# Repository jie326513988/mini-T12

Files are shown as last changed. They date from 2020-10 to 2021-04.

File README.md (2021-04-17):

# Mini T12焊台-基于Arduino平台-Atmege328p-au
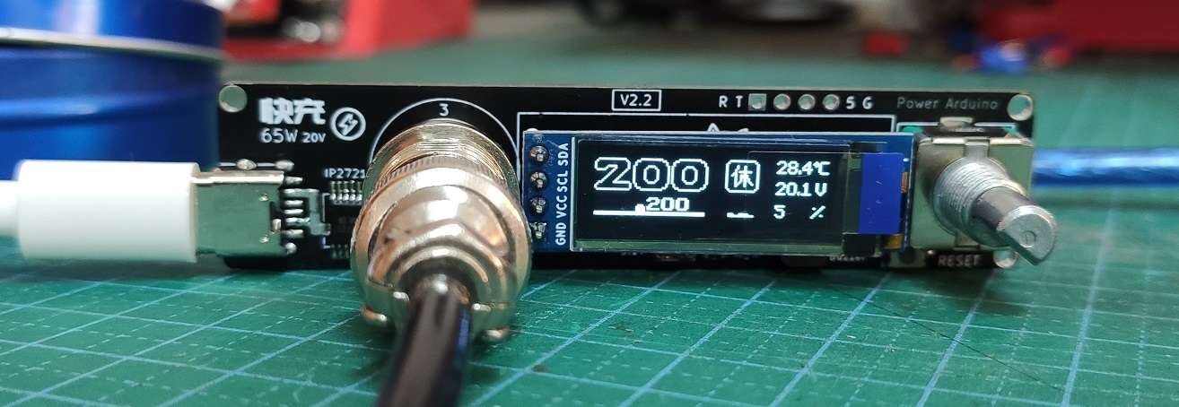
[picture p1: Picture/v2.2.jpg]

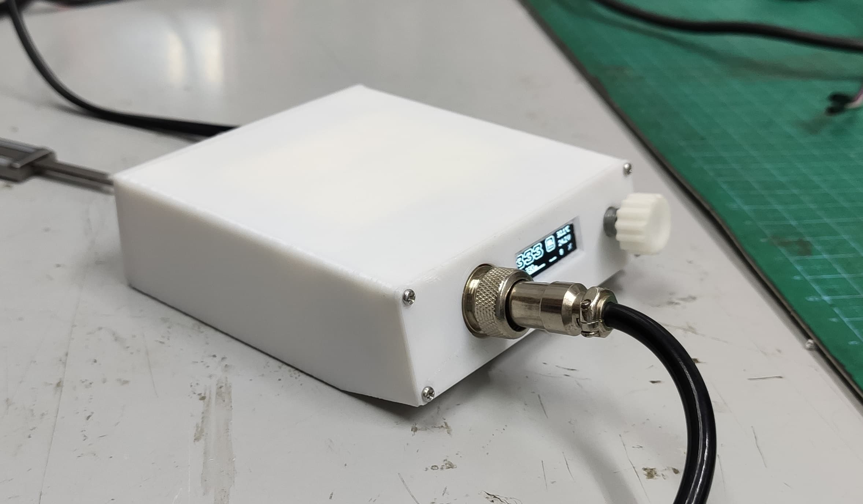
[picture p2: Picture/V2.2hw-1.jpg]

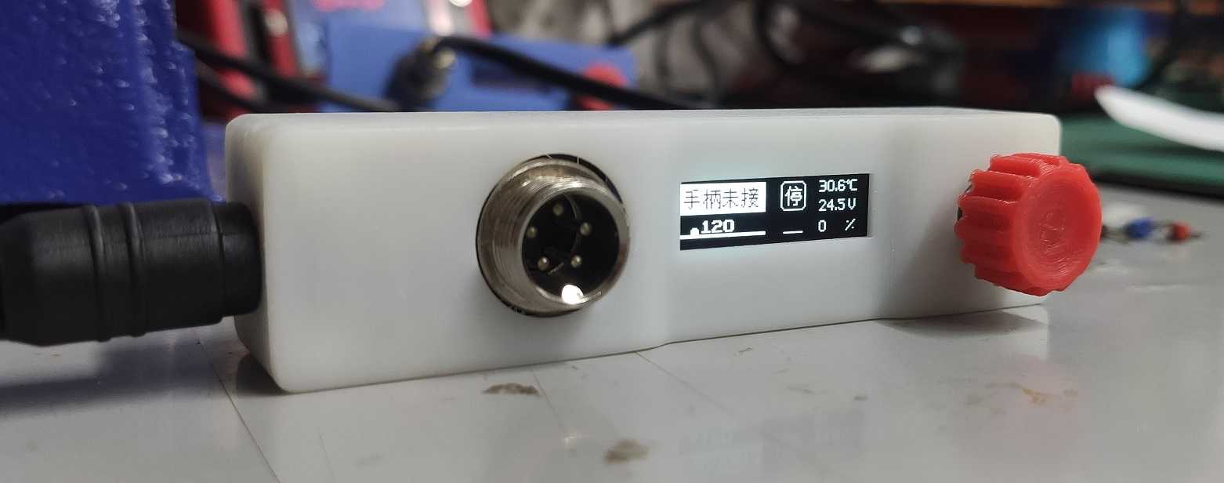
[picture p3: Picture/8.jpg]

### 2021-04-17 V2.2适配华为音响电源一体版的3D打印外壳文件放出
### 2021-04-14 V2.2pd诱骗版本 需将诱骗芯片处100K电阻（接地的那一颗）改为300K，另外一颗不需要改。
### 2021-03-21 V1.20程序更新
* 1.修正温度动画

### 2021-03-20 V1.20程序更新
* 1.主界面温度添加线性化动画
* 2.修改蜂鸣器端口配置策略，停止后改为输入模式
* 3.缩小字库删减不需要的字符并将字库放在本地调用
* 4.休眠时间可以关闭，小于30秒为关闭

#### 默认支持深圳头，更换其他厂商的头需要自行校准温度曲线
#### 一定要使用我提供的U8g2库，否者无法显示中文和提示内存过大无法编译
#### 缺点就是PID温控超调回正时间过长，有能力的小伙伴可自己调节pid参数。
#### 本人喜欢温度显示真实一点，故采用显示平均温度的方案（8次温度采样的平均值）。
#### 当设定温度和平均温度的差值<=3度时就显示平均温度，所以看着会上下浮动1-2度是正常的。
#### 新烙铁头要经过老化温度才能稳定
* 可以在菜单设置里旋转屏幕显示的方向，方便不同的人群
* 动态调参PID
* 稳定时显示5次采集到的平均温度，其他时候显示实时温度大概500ma刷新一次
* 取消电流传感器，主界面取消电流显示改为显示PWM百分比
* 使用4段温度拟合温度曲线，4项式公式计时，可在设置菜单“校准”选项调整
* 休眠计时和息屏倒计时改用定时器2计时
* 息屏显示，无加热无操作3分钟后进入，息屏时显示环境温度，随机平滑移动
* 开机提示音和平滑过渡的开机界面
* 休眠时自动保存当前设置温度到eeprom
* 待机功耗8.8ma 息屏待机功耗6.4ma（24）
#### 观看视频 https://www.bilibili.com/video/BV1vf4y1B7Xa
#### 按键功能定义
* 长按操作（5下短音最后1下长音）
  * 主界面，进入设置界面
  * 其他界面，退出至主界面
* 双击操作（2下短音）
  * 主界面，加热或停止状态切换
  * 其他界面，无
* 单击（1下短音）
  * 主界面，无
  * 设置界面，进入二级菜单
  * 二级菜单，切换数值更改选中状态，或确认更改数值，无选框状态则退出至一级菜单
#### 菜单选项
* PID
  * P
  * I
  * D
* 休眠
  * 休眠时间
  * 休眠温度
* 屏幕
  * 屏幕亮度
  * 屏幕方向
  * 编码器方向
* 电源
  * 基准电压
  * 电源电压
  * 低压报警
* 校准
  * 调节曲线第1段温度
  * 调节曲线第2段温度
  * 调节曲线第3段温度
  * 调节曲线第4段温度
  * 运行曲线拟合程序校准温度曲线
* 烙铁
  * 冷端补偿
  * 开机加热
  * 重置
#### 校准温度曲线的方法
* 1.先校准基准电压，测量串口的5V接口就是基准电压
* 2.准备好能测量0-500摄氏度的设备，探头建议使用裸装，以免外壳热传导导致热量损失测量不准
* 3.将探头紧压住烙铁头发热前段（上锡部分再下来一点），一定要紧紧压住，不然也会测量不准
* 4.放置好烙铁头以免校准时烫伤手或物品！
* 5.接上电源，进入‘烙台’界面，将室温设置为当前的冷端补偿温度，再进入‘校准’界面，将空心选框移动至第1段温度处（即对应的ADC 10下面）
* 6.按下确认键，此时空心选框变成实心选框，烙铁头开始加热，等待最下方的‘Now ADC’值稳定在一定的范围，与第一行相应的ADC值差不多即可（此时是ADC 10）
* 7.使用测量设备测量烙铁头的温度，将第1段温度调至测量得到的温度（实心选框状态可旋转旋钮调节数值）
* 8.依次测量剩下的第2段、第3段、第4段温度并输入至控制器
* 9.测量完4段温度后将光标移至Save，按下确认键，等待程序计时温度曲线
* 10.计算完会显示P系数界面，，再按下确认键即可退出校准界面
* 11.在主界面准备进行二次校准
* 12.在主界面开启加热至第二段校准的温度，如265，则加热至260度，若不对则进入校准界面加减对应的计算温度，直至自己满意为止。
* 13.依次加热至第三、第四、第一、第四段温度并校准，直至自己满意为止。

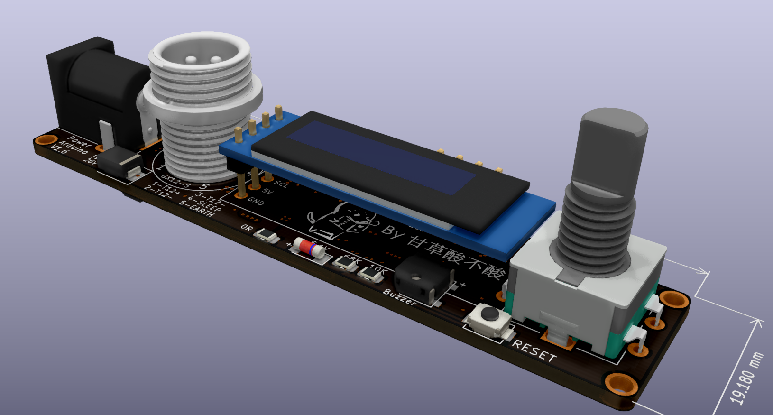
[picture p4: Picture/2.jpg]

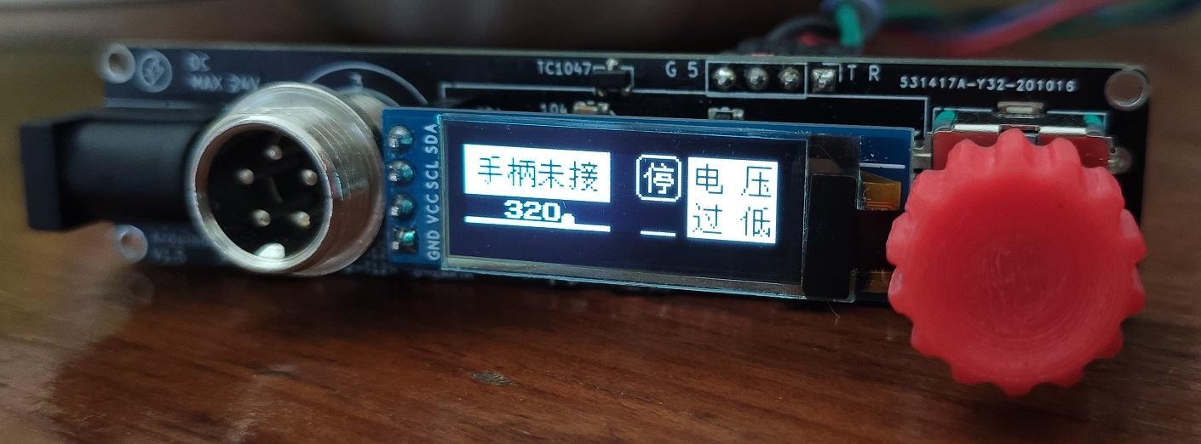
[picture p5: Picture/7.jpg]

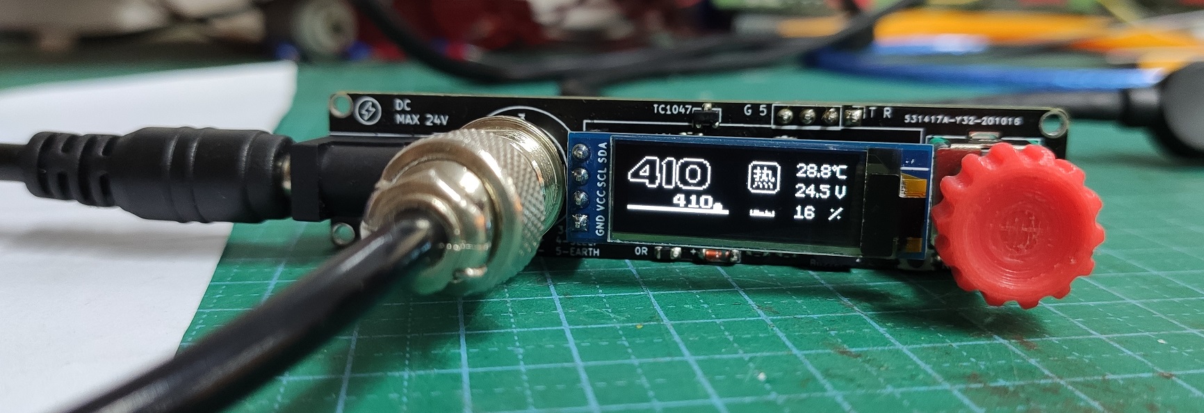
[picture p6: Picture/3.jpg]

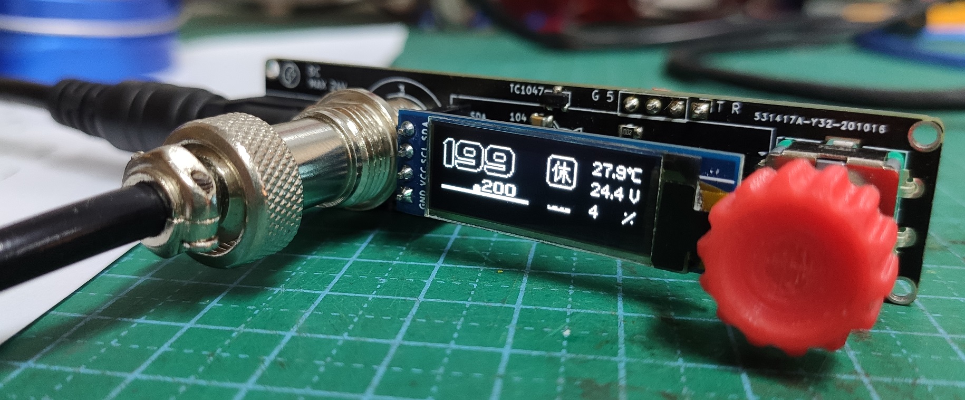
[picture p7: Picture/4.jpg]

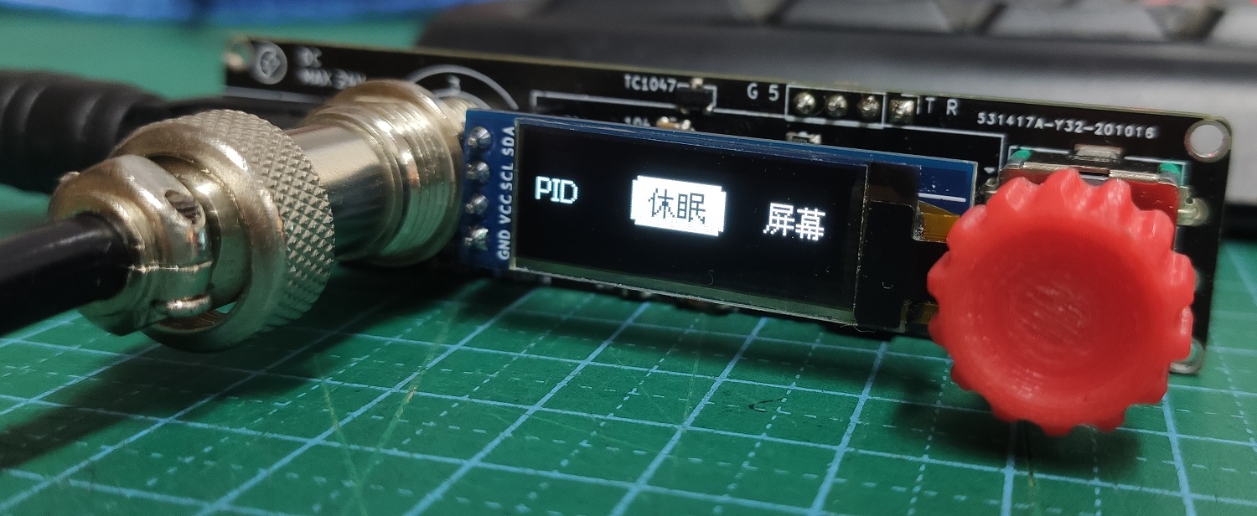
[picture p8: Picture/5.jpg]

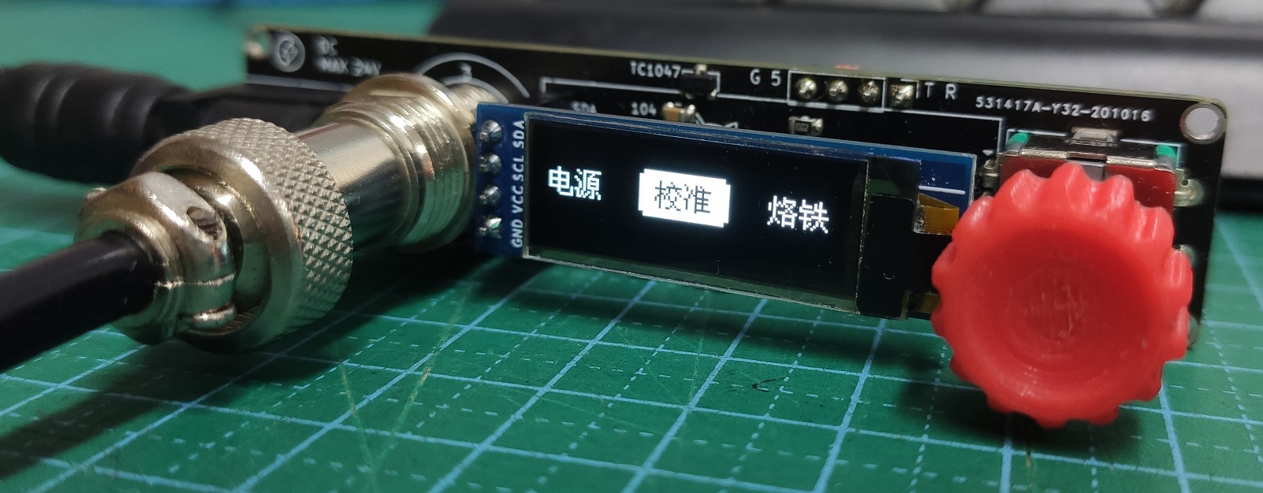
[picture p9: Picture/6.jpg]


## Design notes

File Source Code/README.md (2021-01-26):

## pcb v2.2以后的版本只能使用V1.1以上的程序
## 程序1.03为V1.X的pcb使用

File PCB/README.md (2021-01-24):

#### V2.2pd诱骗版本，优化DCDC线路不烧芯片。

#### 元件要求
* 所有电容首选X7R为佳，其次X5R，千万不要选择Y5V
* DCDC的10UF输入电容使用耐压35V以上
* LP2985的105、104输入电容选择耐压16V以上
* 运放的采样电阻33KΩ和10KΩ使用0.1%精度
* 电压采样电阻68K和10K使用1%精度
* C10,C12,C18耐压16V以上
* 104电容通通耐压50V就行，222电容也耐压50V
* 电阻电容选择0603封装更好焊接
* 磁珠100MHZ阻抗1K,电流100ma以上

#### 用了V1.7PCB的朋友请看下面即可正常使用
* 移除26V的TVS管（D3）
* 移除靠近单片机的10uh电感，改成直连
* 三极管附近的10Ω（R3）电阻改为4.7KΩ，10KΩ电阻改为4.7KΩ（R4）

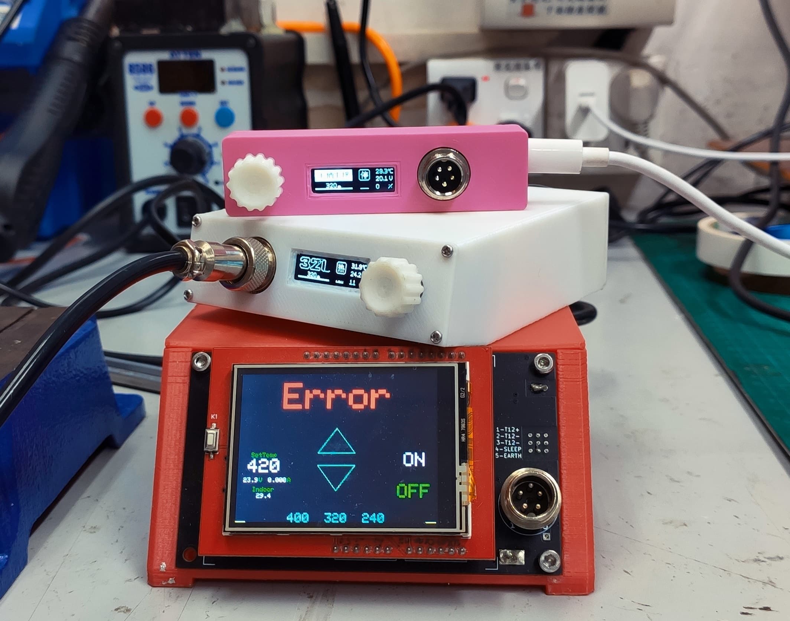
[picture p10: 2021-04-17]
Picture/qjf.jpg

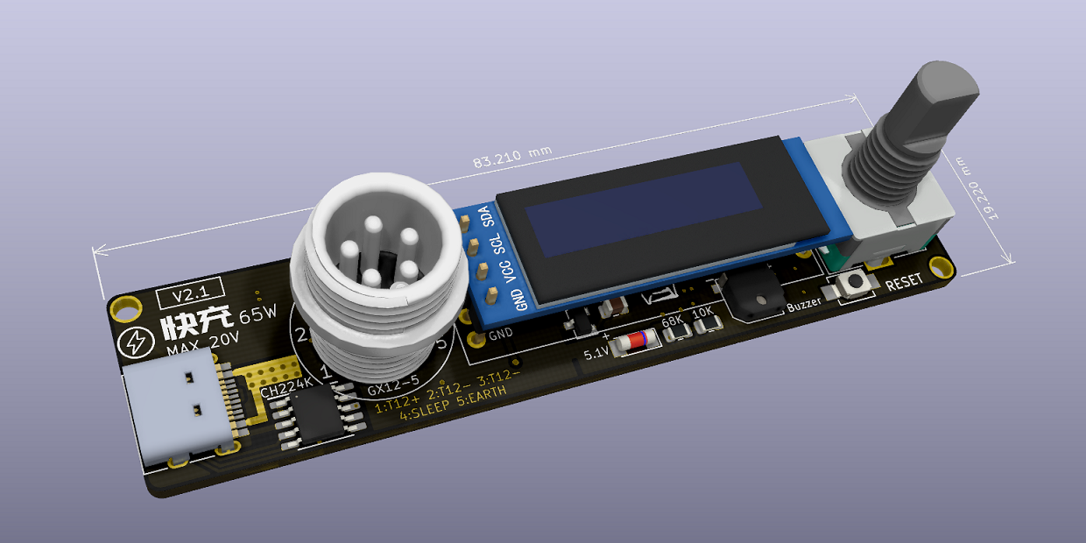
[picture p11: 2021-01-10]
Picture/65W.jpg

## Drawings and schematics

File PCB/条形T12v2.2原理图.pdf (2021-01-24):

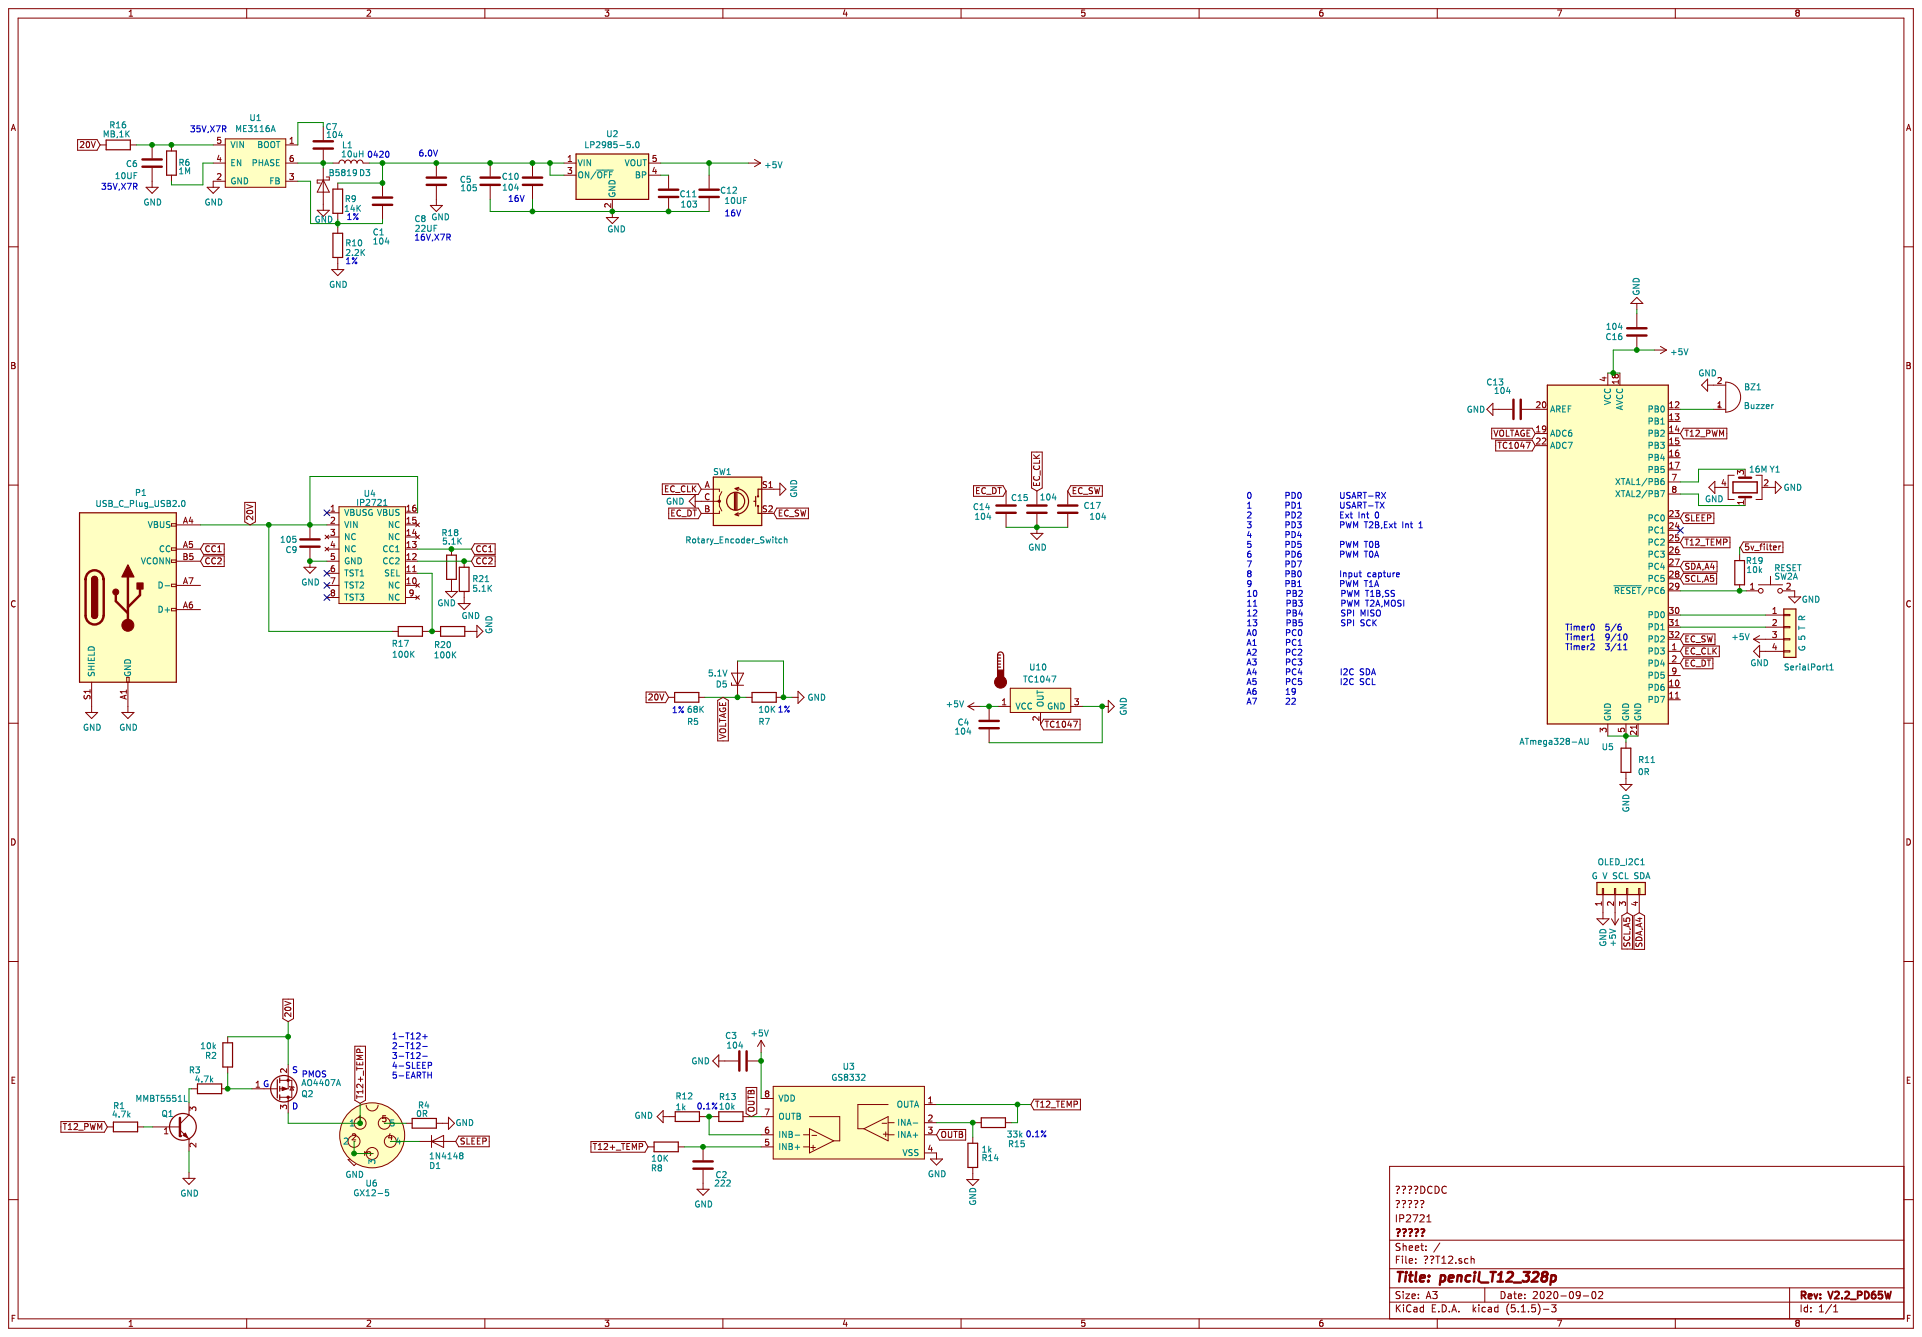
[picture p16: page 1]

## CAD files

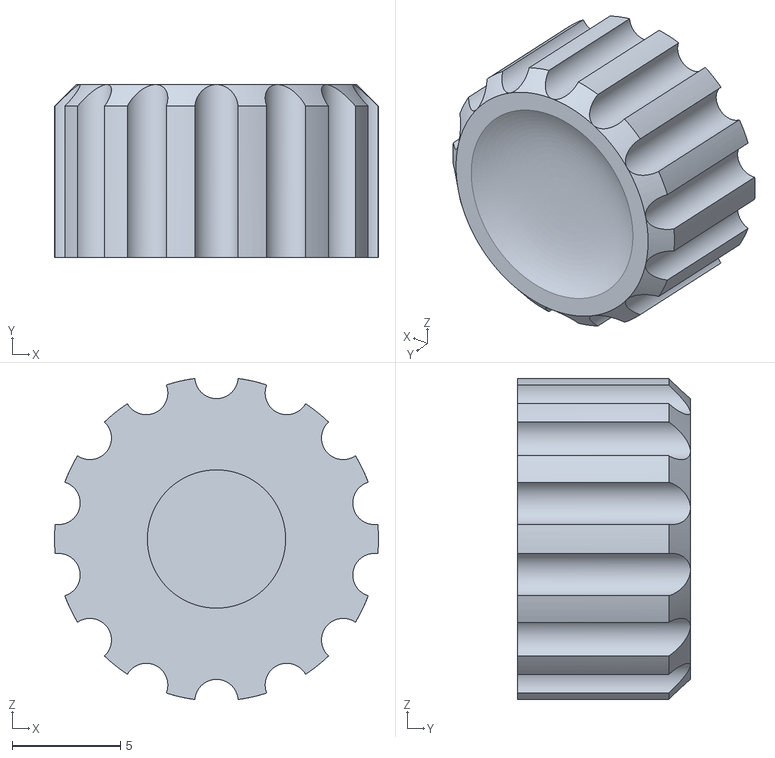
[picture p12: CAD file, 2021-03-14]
3D Printing/旋转编码器旋钮-圆型.STL
15.0 x 8.00 x 14.9

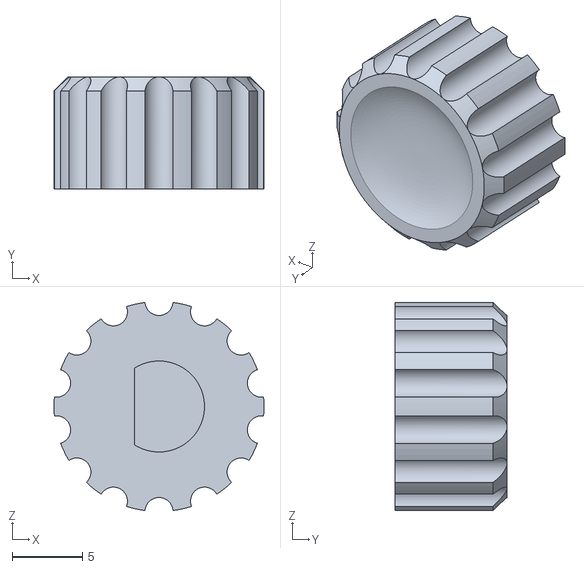
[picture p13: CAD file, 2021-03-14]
3D Printing/旋转编码器旋钮-D型.STL
15.0 x 8.00 x 14.9

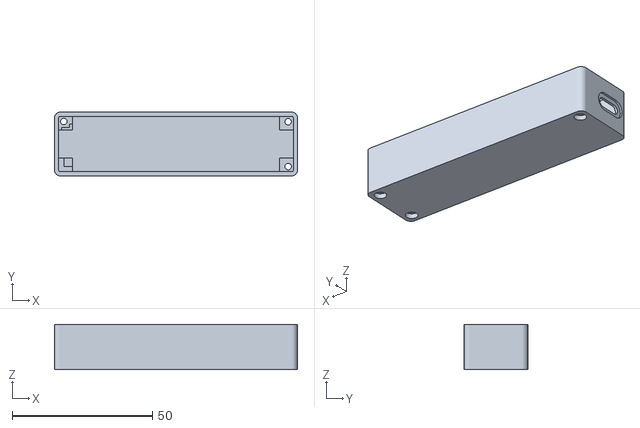
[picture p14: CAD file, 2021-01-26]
3D Printing/V2.2底壳_TYPEC.STL
86.7 x 22.7 x 16.1

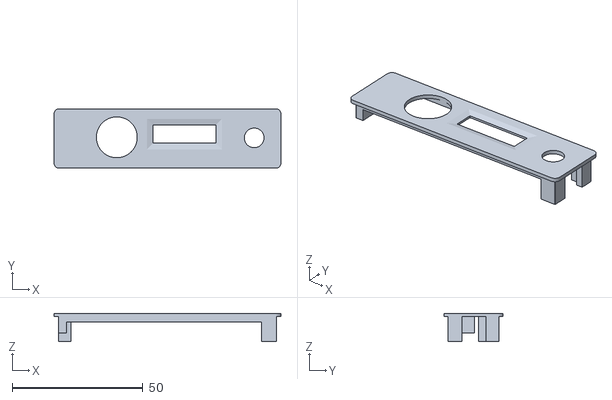
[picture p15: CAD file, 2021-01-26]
3D Printing/V2.2盖子_TYPEC.STL
86.7 x 22.7 x 10.9
